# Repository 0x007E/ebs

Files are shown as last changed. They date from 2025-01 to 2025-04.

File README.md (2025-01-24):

  

# `EBS` - Ethernally Blink Solar (Ewigblink)

The `EBS` project is based on a pcb with photodiodes ([PB333](#additional-information)) and a supercap ([HV0810](#additional-information)) with `1F` so that in combination with sunlight the state of the led starts changing.

| Experience | Level |
|:---|:-----:|
| Soldering | 25% |
| Mechanical  | 20% |

# Downloads

| Type | File | Description |
|:---:|:---:|:---|
| Simulation | [asc](https://github.com/0x007E/ebs/raw/refs/heads/main/EBS.asc) | LTSpice Simulation | 
| Lochmaster | [lm4](https://github.com/0x007E/ebs/raw/refs/heads/main/EBS.LM4) | Stripe grid circuit board | 
| Schematic | [pdf](https://github.com/0x007E/ebs/releases/latest/download/schematic.pdf) / [cadlab](https://cadlab.io/project/28595/main/files) | Schematic files |
| Board | [pdf](https://github.com/0x007E/ebs/releases/latest/download/pcb.pdf) / [cadlab](https://cadlab.io/project/28595/main/files) | Board file |
| Drill | [pdf](https://github.com/0x007E/ebs/releases/latest/download/drill.pdf) | Drill file |
| PCB | [zip](https://github.com/0x007E/ebs/releases/latest/download/kicad.zip) / [tar](https://github.com/0x007E/ebs/releases/latest/download/kicad.tar.gz) | KiCAD/Gerber/BoM/Drill files |
| Mechanical | [zip](https://github.com/0x007E/ebs/releases/latest/download/freecad.zip) / [tar](https://github.com/0x007E/ebs/releases/latest/download/freecad.tar.gz) | FreeCAD/Housing and PCB (STEP) files |

# Hardware

There are two parts of the hardware. The pcb and the housing of the `EBS`. The pcb is created with `KiCAD` and the housing with `FreeCAD`. All files are built with `github actions` so that they are ready for a production environment. The housing is printed with a 3D-printer (`Dremel 3D40`).

## PCB

The circuit board is populated on one side (Top). The best way for soldering is within a standard soldering system.

### Top Layer

Top Layer

### Bottom Layer

Bottom Layer

## Mechanical

The housing has a tolerance of `0.2mm` on each side of the case. So the pcb should fit perfectly in the housing.

### Assembled

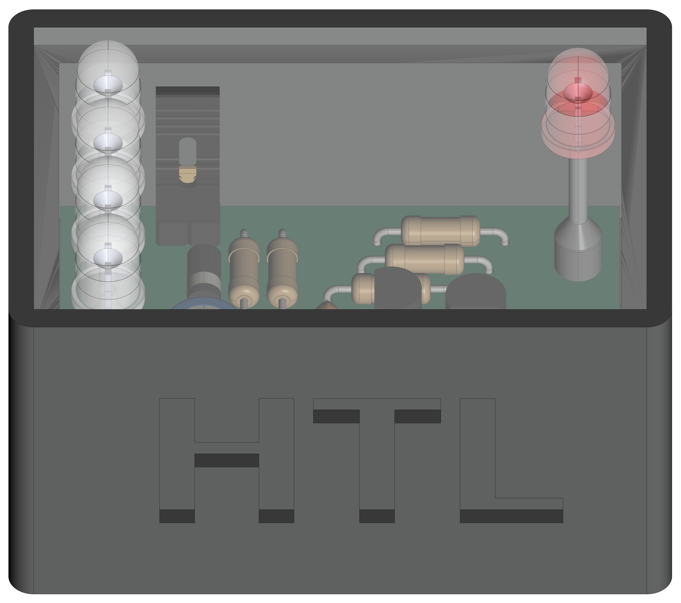
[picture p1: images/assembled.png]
Assembled


#### Exploded

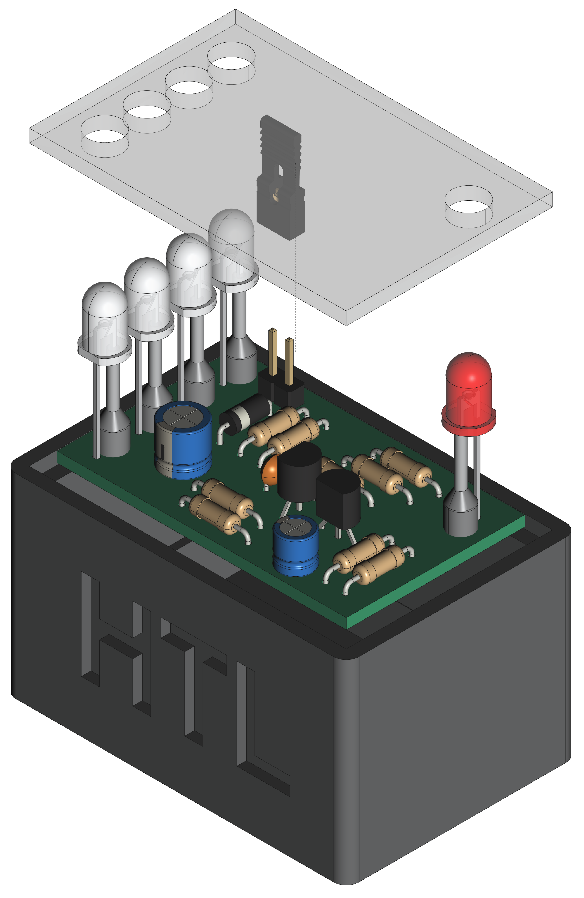
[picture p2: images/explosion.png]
Exploded


# Additional Information

| Type | Link | Description |
|:---:|:---:|:---|
| PB333 | [pdf](https://www.everlighteurope.com/custom/files/datasheets/DPD-0000154.pdf) | Photodiode |
| HV0810 | [pdf](https://www.eaton.com/content/dam/eaton/products/electronic-components/resources/data-sheet/eaton-hv-supercapacitors-cylindrical-cells-data-sheet.pdf) | Supercap |)

---

R. GAECHTER

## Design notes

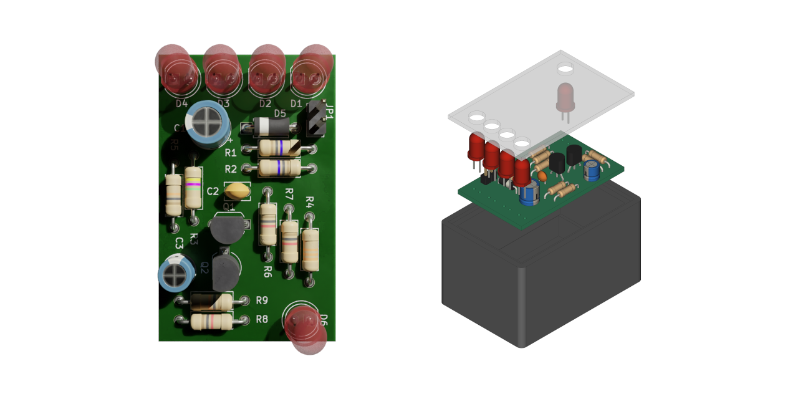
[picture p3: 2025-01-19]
images/social.png

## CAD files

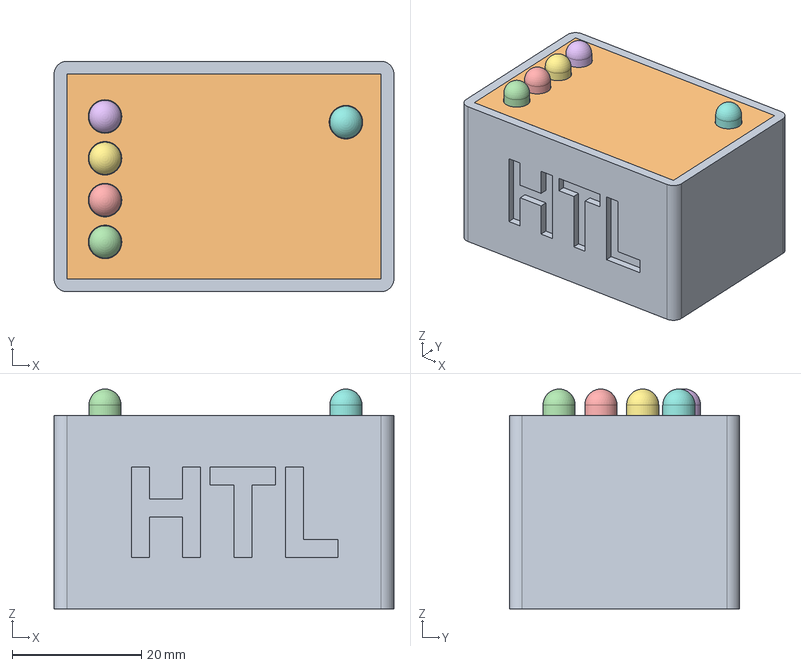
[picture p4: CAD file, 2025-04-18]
mechanical/housing.FCStd
52.7 x 35.7 x 34.1 mm
Pcb_f765
R6_R_Axial_DIN0207_L63mm_D25mm_P1016mm_Horizontal_7b49e6c67002
Glass Round 5mm
Pin One MKIII
Pin Two MKIII
Aderenhülse 0,75 qmm x 8 mm - teilisoliert grau
Aderenhülse 0,75 qmm x 8 mm - teilisoliert grau001
Q1_TO-92_Inline_Wide_6bc2e730dc35
JP1_PinHeader_1x02_P254mm_Vertical_0ba5d17b514c
JP1_AKSPLTG-BLACK_0ba5d17b514c[2]
R4_R_Axial_DIN0207_L63mm_D25mm_P1016mm_Horizontal_dc7c0994a6b1
C2_C_Disc_D38mm_W26mm_P250mm_d276c54571e3
R8_R_Axial_DIN0207_L63mm_D25mm_P1016mm_Horizontal_cc6253b91278
Glass Round 5mm001
Pin One MKIII001
Pin Two MKIII001
Aderenhülse 0,75 qmm x 8 mm - teilisoliert grau002
Aderenhülse 0,75 qmm x 8 mm - teilisoliert grau003
D5_D_A-405_P7.62mm_Horizontal_2b55be18c7aa
R2_R_Axial_DIN0207_L63mm_D25mm_P1016mm_Horizontal_df98f919c602
Glass Round 5mm002
Pin One MKIII002
Pin Two MKIII002
Aderenhülse 0,75 qmm x 8 mm - teilisoliert grau004
Aderenhülse 0,75 qmm x 8 mm - teilisoliert grau005
Glass Round 5mm003
Pin One MKIII003
Pin Two MKIII003
Aderenhülse 0,75 qmm x 8 mm - teilisoliert grau006
Aderenhülse 0,75 qmm x 8 mm - teilisoliert grau007
C3_CP_Radial_D50mm_P250mm_494a631df1a2
R5_R_Axial_DIN0207_L63mm_D25mm_P1016mm_Horizontal_7367afe615f3
R7_R_Axial_DIN0207_L63mm_D25mm_P1016mm_Horizontal_6995945d858d
R9_R_Axial_DIN0207_L63mm_D25mm_P1016mm_Horizontal_6fdbd29a4690
Q2_TO-92_Inline_Wide_7161153e3209
Glass Round 5mm004
Pin One MKIII004
Pin Two MKIII004
Aderenhülse 0,75 qmm x 8 mm - teilisoliert grau008
Aderenhülse 0,75 qmm x 8 mm - teilisoliert grau009
C1_CP_Radial_D63mm_P250mm_729b3dd5fbce
R1_R_Axial_DIN0207_L63mm_D25mm_P1016mm_Horizontal_e9c9cc486bcb
R3_R_Axial_DIN0207_L63mm_D25mm_P1016mm_Horizontal_097cf9ba556d

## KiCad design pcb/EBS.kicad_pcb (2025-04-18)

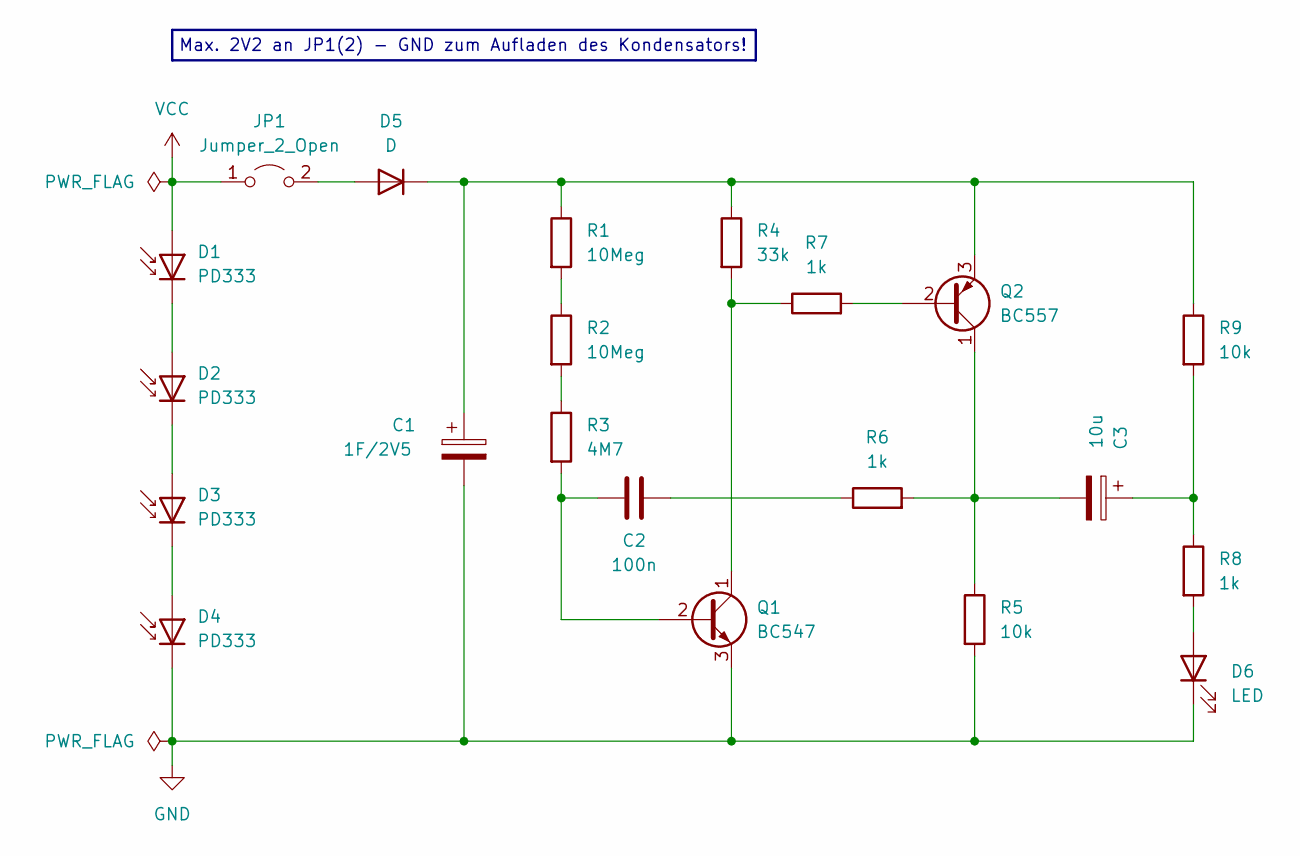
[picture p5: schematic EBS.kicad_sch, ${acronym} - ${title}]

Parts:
C1: 1F/2V5; CP_Radial_D6.3mm_P2.50mm
C2: 100n; C_Disc_D3.8mm_W2.6mm_P2.50mm
C3: 10u; CP_Radial_D5.0mm_P2.50mm
D1, D2, D3, D4: PD333; LED_D5.0mm
D5: D; D_A-405_P7.62mm_Horizontal
D6: LED; LED_D5.0mm
JP1: Jumper_2_Open; PinHeader_1x02_P2.54mm_Vertical
Q1: BC547; TO-92_Inline_Wide
Q2: BC557; TO-92_Inline_Wide
R1, R2: 10Meg; R_Axial_DIN0207_L6.3mm_D2.5mm_P10.16mm_Horizontal
R3: 4M7; R_Axial_DIN0207_L6.3mm_D2.5mm_P10.16mm_Horizontal
R4: 33k; R_Axial_DIN0207_L6.3mm_D2.5mm_P10.16mm_Horizontal
R5, R9: 10k; R_Axial_DIN0207_L6.3mm_D2.5mm_P10.16mm_Horizontal
R6, R7, R8: 1k; R_Axial_DIN0207_L6.3mm_D2.5mm_P10.16mm_Horizontal

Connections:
GND: C1.2, D4.1 (K), D6.1 (K), Q1.3 (E), R5.2
unnamed: C2.2, R6.1
unnamed: C3.1, R8.1, R9.2
unnamed: D1.1 (K), D2.2 (A)
unnamed: D2.1 (K), D3.2 (A)
unnamed: D3.1 (K), D4.2 (A)
unnamed: D5.2 (A), JP1.2 (B)
unnamed: C1.1, D5.1 (K), Q2.3 (E), R1.1, R4.1, R9.1
unnamed: D6.2 (A), R8.2
unnamed: C2.1, Q1.2 (B), R3.2
unnamed: Q1.1 (C), R4.2, R7.1
unnamed: Q2.2 (B), R7.2
unnamed: C3.2, Q2.1 (C), R5.1, R6.2
unnamed: R1.2, R2.1
unnamed: R2.2, R3.1
VCC: D1.2 (A), JP1.1 (A)

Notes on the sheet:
Max. 2V2 an JP1(2) - GND zum Aufladen des Kondensators!

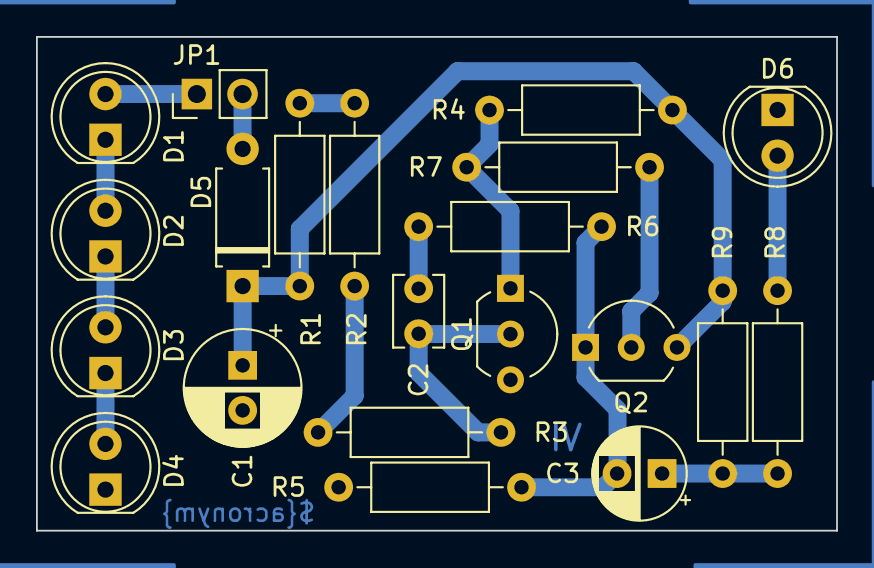
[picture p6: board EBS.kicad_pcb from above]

Board: 2 copper layers, 44.4 x 27.4 mm, 21 parts (0 on the bottom side), 16 nets.

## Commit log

2025-01-19 Add missing text and parts
    [housing.FCStd]
2025-01-19 Add value to BOM
2025-01-24 Fix path and explosion drawing
    [housing.FCStd]
2025-01-24 Add TechDraw
    [housing.FCStd]
2025-01-24 Add housing to artifacts
2025-02-21 Change pcb scaling for pdf
2025-04-09 Change resistor unit
    [EBS.kicad_pcb, EBS.kicad_sch]
2025-04-18 Add resistor options
2025-04-18 Extend information text
    [EBS.kicad_sch]
2025-04-18 Change 3d models
    [EBS.kicad_pcb]
2025-04-18 Ignore footprint missmatch
2025-04-18 Change ferrule on leds
    [EBS.kicad_pcb]
2025-04-18 Add jumper model to JP1
    [EBS.kicad_pcb]
2025-04-18 Update 3d models on pcb
    [housing.FCStd]
2025-04-18 Change led models
    [EBS.kicad_pcb]
2025-04-18 Switch to updated led models
    [housing.FCStd]
2025-04-18 Disable visibility of trajectory line
    [housing.FCStd]
2025-04-18 Fix BOM integration
    [EBS.kicad_pcb, EBS.kicad_sch]

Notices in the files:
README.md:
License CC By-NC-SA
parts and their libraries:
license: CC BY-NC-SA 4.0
